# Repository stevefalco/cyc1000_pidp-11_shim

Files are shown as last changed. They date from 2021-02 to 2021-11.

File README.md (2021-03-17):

# cyc1000 pidp-11 shim
This shim allows a PDP-2011 CYC1000 FPGA implementation of the PDP-11 to be used with a PiDP-11 panel.

The PDP2011 FPGA is described here:  https://pdp2011.sytse.net/wordpress/pdp-11/fpga-boards/cyc1000/

The PiDP-11 is described here:  https://obsolescence.wixsite.com/obsolescence/pidp-11

This shim PCB is viewed from the top.  It directly plugs onto the back of the PiDP-11 PCB.  I designed this shim because I had electrical noise problems that caused Ethernet glitches.  I traced the problem to the cables between the CYC1000 and the Digilent Ethernet and SD modules.  This shim eliminates the cables and allows the Digilent modules to connect directly to the shim PCB.

Here are two views of the assembled PCB, showing the Digilent modules extending vertically from the PCB.

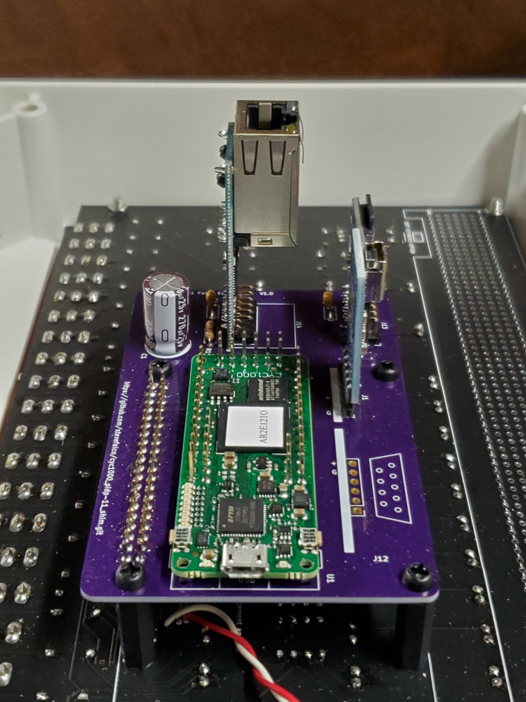
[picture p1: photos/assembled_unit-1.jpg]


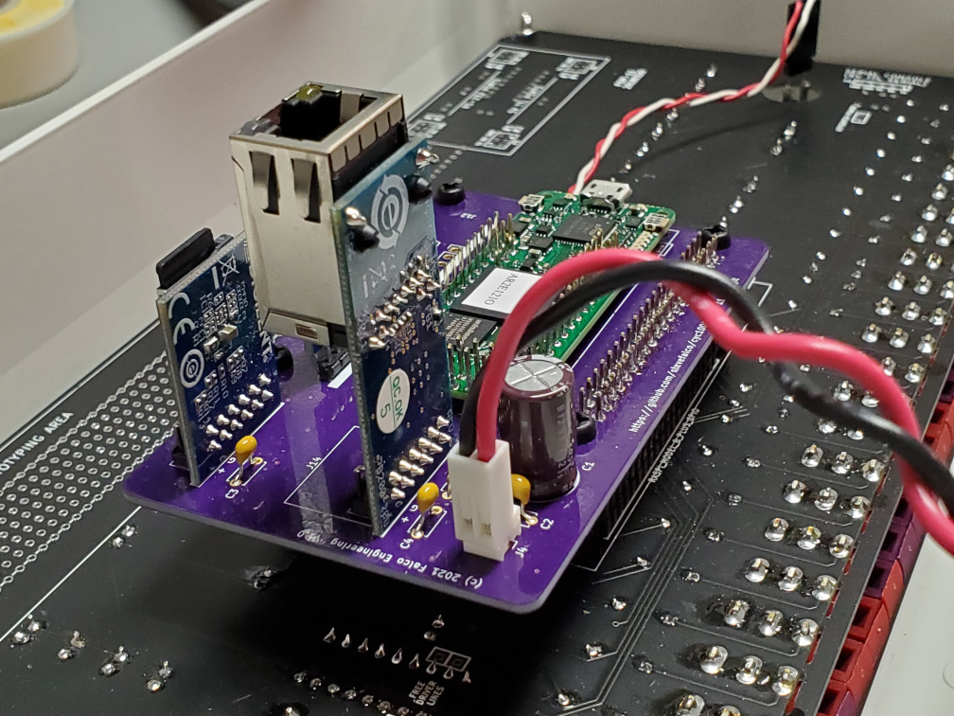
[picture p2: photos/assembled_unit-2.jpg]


J11 must be installed on the bottom of this PCB in order to properly mate with the PiDP-11.  The CYC1000 and all other parts are installed on the top of this PCB.

All capacitors are optional.  I personally prefer to include them.  For C1, the square pad is the positive terminal and the round pad is the negative terminal.

R1 is optional, but according to the Microchip data sheet for the ENC424J600 (see figure 2-9) it really should be installed.

You can only install J1 (FTDI-Friend) or J12 (RS232 PMOD), not both, to avoid conflicts driving the RX1 signal.  In the photos above I installed the FTDI-Friend.

I also designed a housing, suitable for 3D printing, to fit over the modules, since they are of different heights, and they extend through the back panel of the PiDP-11.  The housing named "cover_ftdi_friend.stl" assumes that you will be using an FTDI Friend rather than an RS232 PMOD.  I removed the female connector from the FTDI Friend, and added a right-angle header, so it could directly solder into the shim.  You will have to modify the housing if you do anything different.  You will find the FreeCAD design file and STL in the housing directory.  Here is a photo:

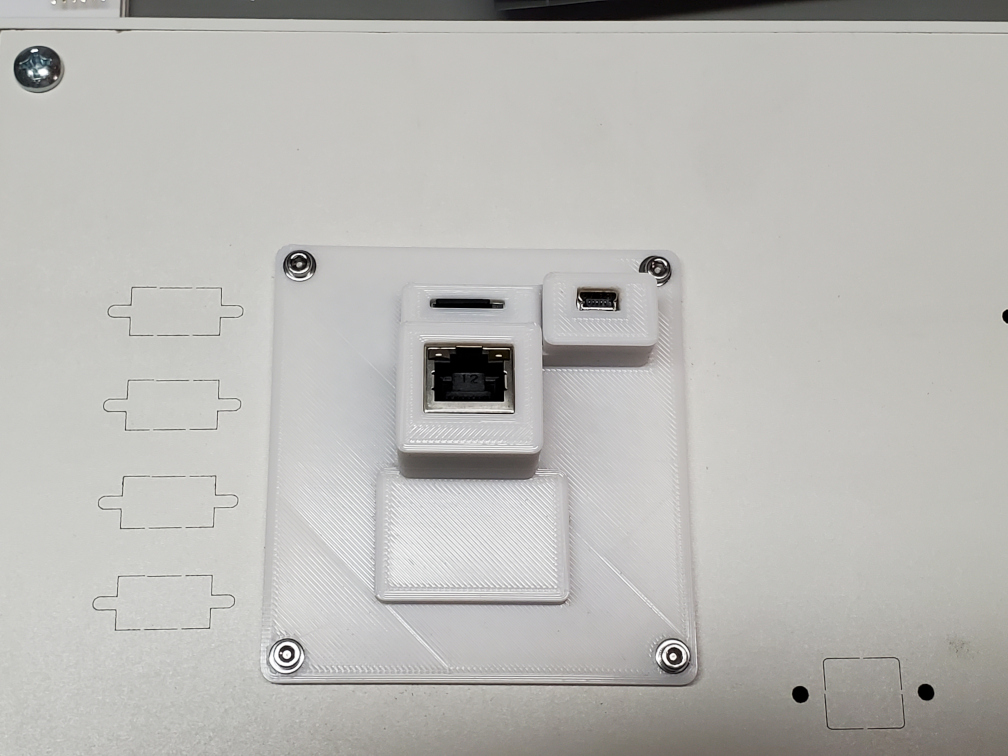
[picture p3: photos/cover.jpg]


There is also a housing named "cover_rs232.stl" which can be used with an RS-232 Digilent PMOD in place of the FTDI friend, if you prefer that interface.

A few last details.  I am using an external power supply rather than powering the unit over USB.  While the CYC1000 allows simultaneous USB and external power - it automatically chooses the higher voltage - I didn't want that, so I modified a bulkhead cable by grinding off the rubber shell at the male end, then cutting the red (+5 volt) connection, and applying epoxy for mechanical strength.  Here is a photo of the modified cable:

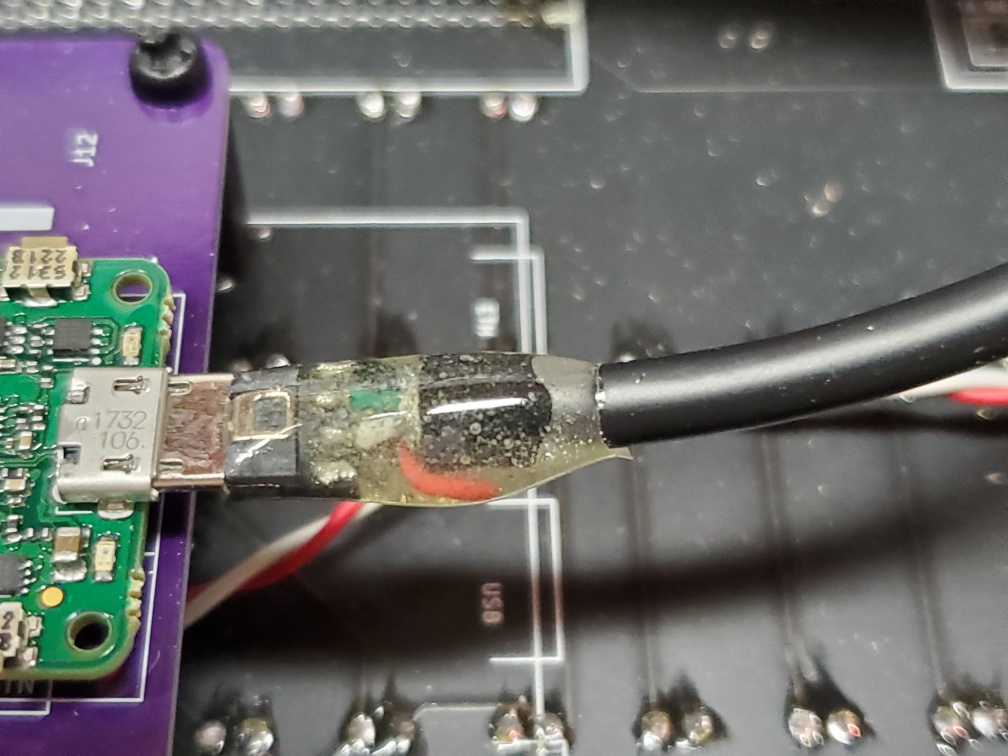
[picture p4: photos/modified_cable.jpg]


And finally, this shim connects the FPGA reset signal to the Pi connector on GPIO19, which has a convenient trace on the PiDP-11 PCB.  In the photos you can see a red/white pair of wires; these connect from GPIO19 to the Key Switch of the front panel.  Thus, the Key Switch can be used to hard-reset the FPGA.

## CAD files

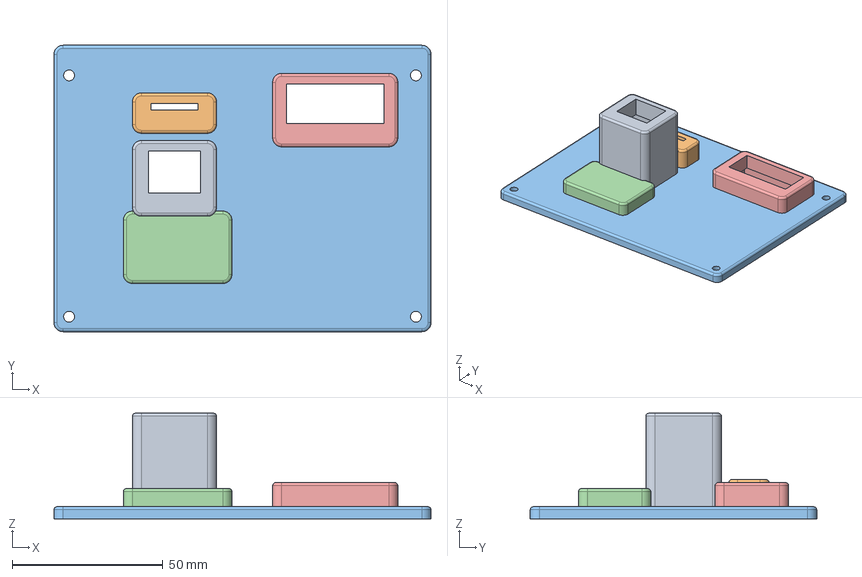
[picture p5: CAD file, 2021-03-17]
housing/cover_rs232.FCStd
125.0 x 95.0 x 35.0 mm
eth_body
sd_body
cover_body
cap_body
rs232_body

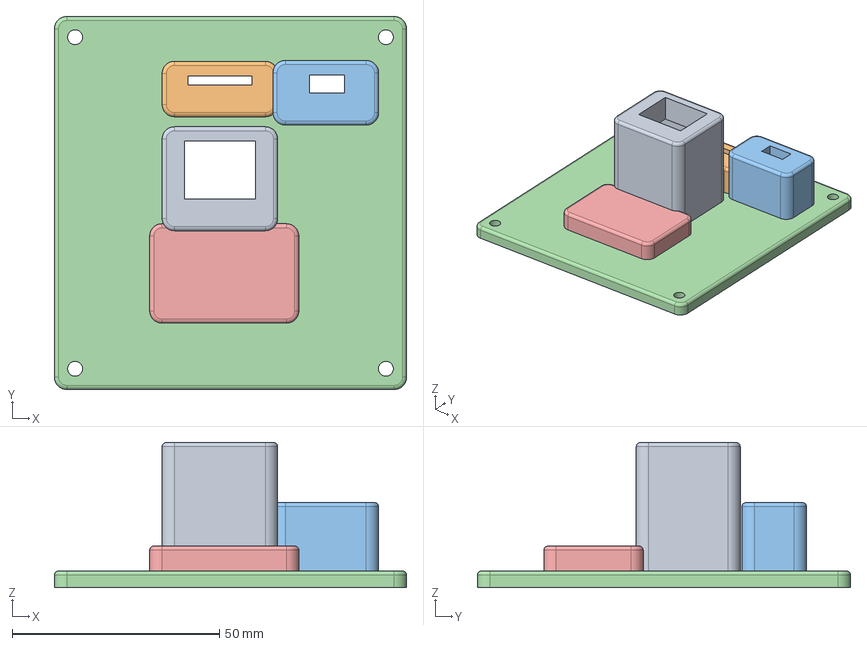
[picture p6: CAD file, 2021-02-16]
housing/cover_ftdi_friend.FCStd
85.0 x 90.0 x 35.0 mm
eth_body
sd_body
friend_body
cover_body
cap_body

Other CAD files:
housing/cover_ftdi_friend.stl
housing/cover_rs232.stl

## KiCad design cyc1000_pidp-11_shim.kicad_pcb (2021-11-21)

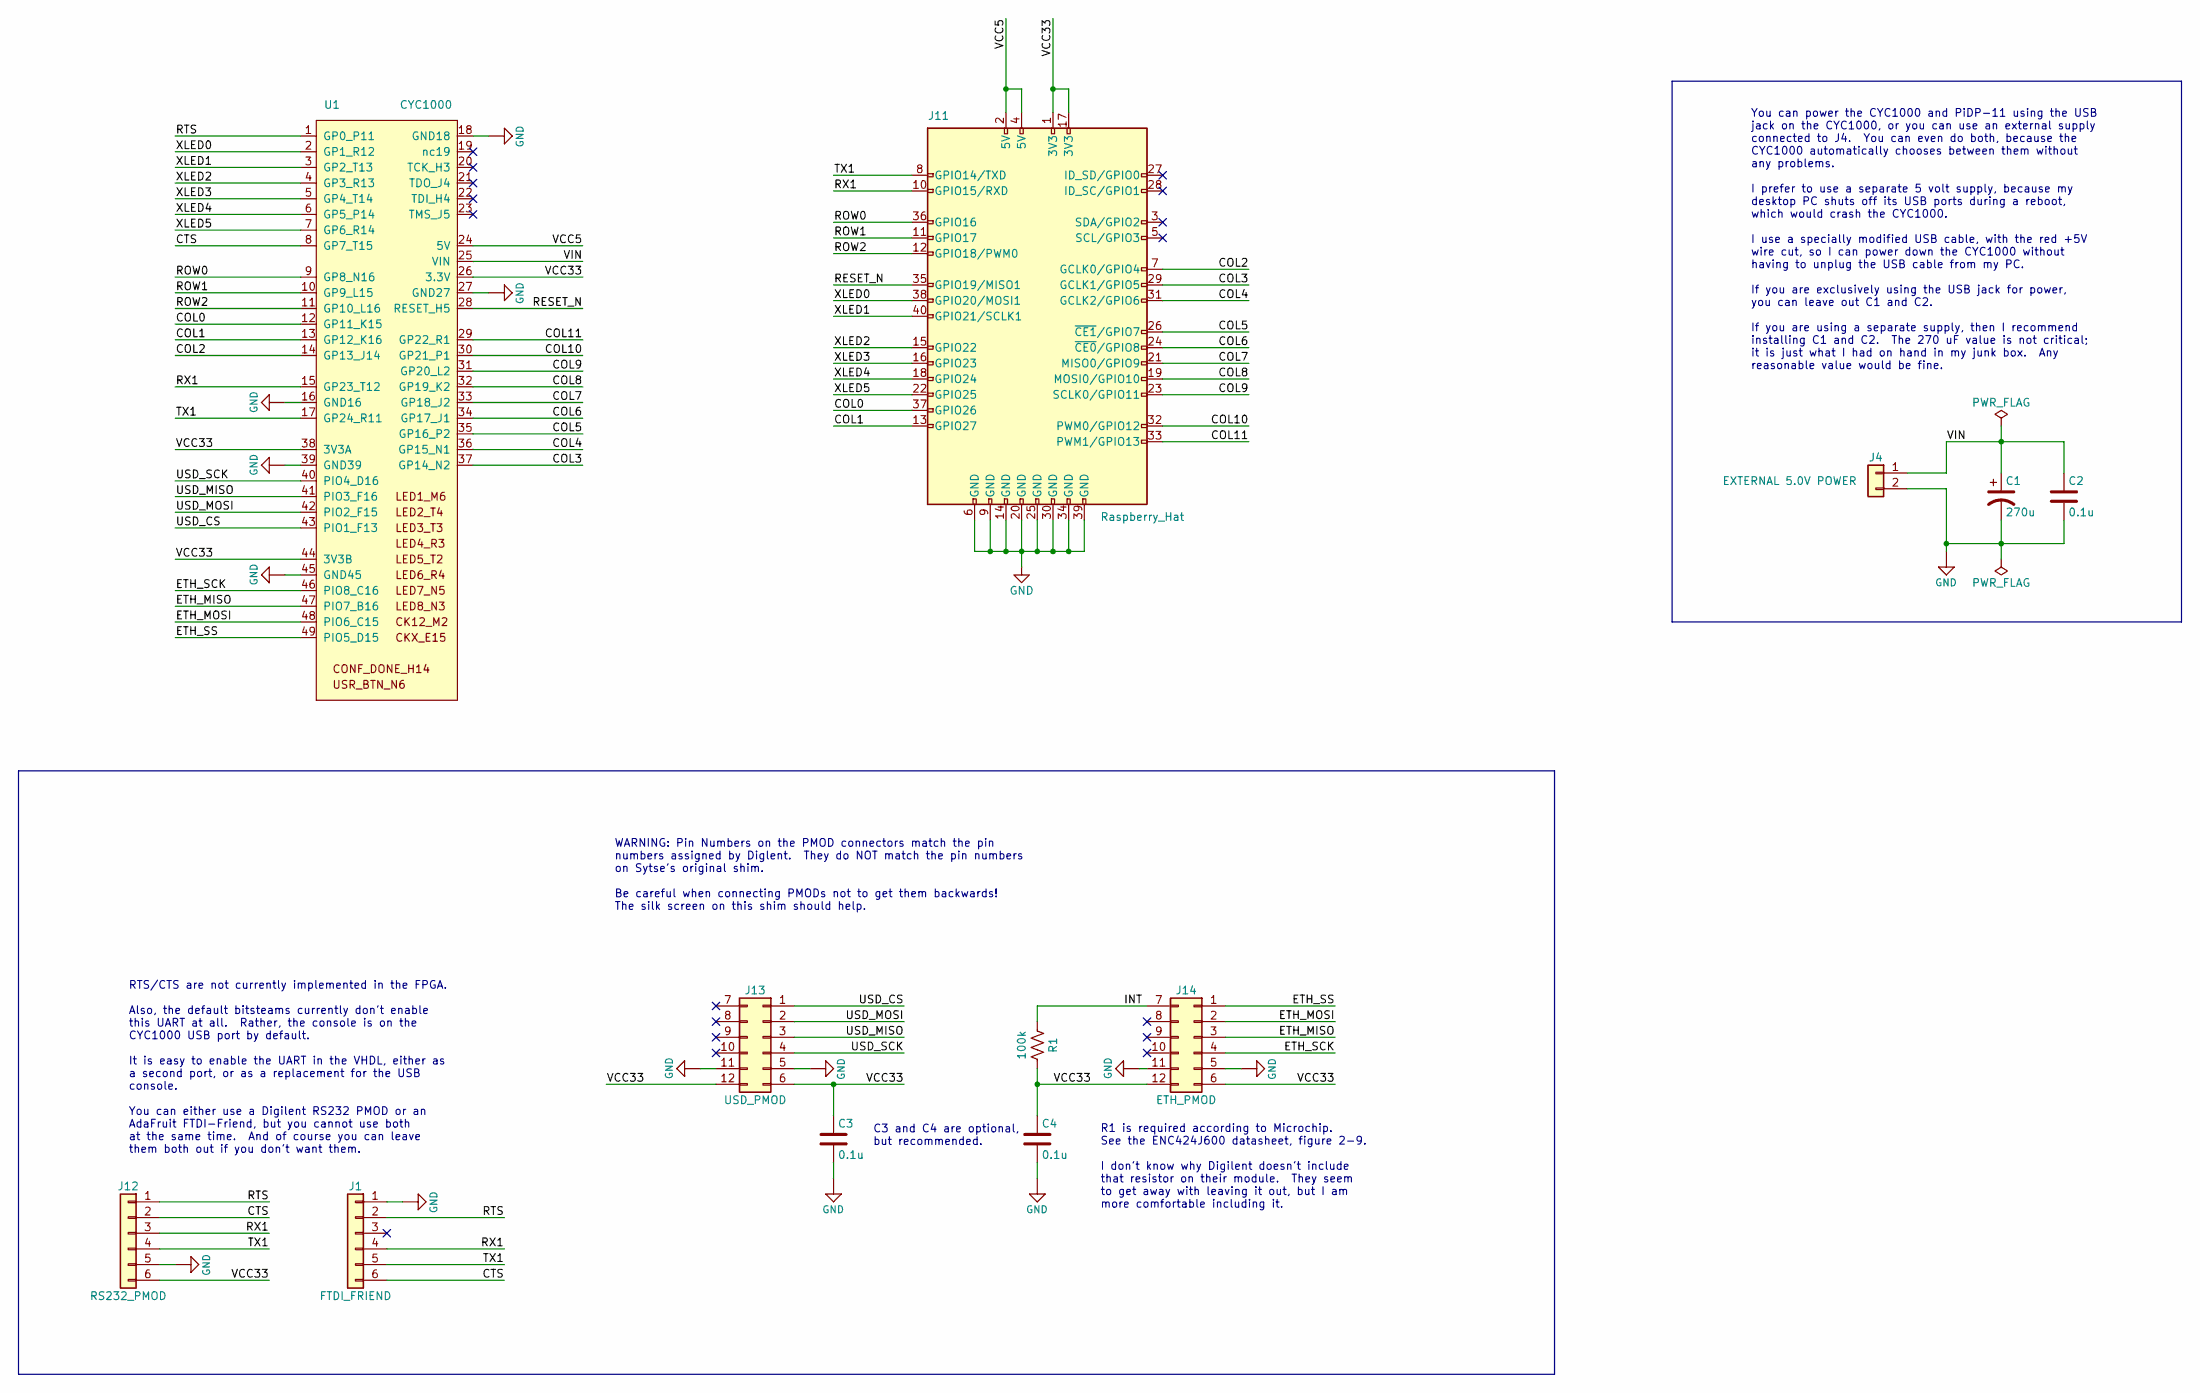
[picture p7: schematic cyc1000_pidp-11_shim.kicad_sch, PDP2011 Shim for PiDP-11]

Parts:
C1: 270u; CP_Radial_D10.0mm_P5.00mm
C2, C3, C4: 0.1u; C_Disc_D5.0mm_W2.5mm_P5.00mm
J1: FTDI_FRIEND; ftdi-friend-1x6
J4: EXTERNAL 5.0V POWER; PinHeader_1x02_P2.54mm_Vertical
J11: Raspberry_Hat; PinHeader_2x20_P2.54mm_Vertical
J12: RS232_PMOD; rs232-1x6
J13: USD_PMOD; uSD-2x6
J14: ETH_PMOD; ethernet-2x6
R1: 100k; R_Axial_DIN0207_L6.3mm_D2.5mm_P7.62mm_Horizontal
U1: CYC1000

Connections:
/COL0: J11.37 (GPIO26), U1.12 (GP11_K15)
/COL1: J11.13 (GPIO27), U1.13 (GP12_K16)
/COL2: J11.7 (GCLK0/GPIO4), U1.14 (GP13_J14)
/COL3: J11.29 (GCLK1/GPIO5), U1.37 (GP14_N2)
/COL4: J11.31 (GCLK2/GPIO6), U1.36 (GP15_N1)
/COL5: J11.26 (~CE1/GPIO7), U1.35 (GP16_P2)
/COL6: J11.24 (~CE0/GPIO8), U1.34 (GP17_J1)
/COL7: J11.21 (MISO0/GPIO9), U1.33 (GP18_J2)
/COL8: J11.19 (MOSI0/GPIO10), U1.32 (GP19_K2)
/COL9: J11.23 (SCLK0/GPIO11), U1.31 (GP20_L2)
/COL10: J11.32 (PWM0/GPIO12), U1.30 (GP21_P1)
/COL11: J11.33 (PWM1/GPIO13), U1.29 (GP22_R1)
/CTS: J1.6, J12.2, U1.8 (GP7_T15)
/ETH_MISO: J14.3, U1.47 (PIO7_B16)
/ETH_MOSI: J14.2, U1.48 (PIO6_C15)
/ETH_SCK: J14.4, U1.46 (PIO8_C16)
/ETH_SS: J14.1, U1.49 (PIO5_D15)
/INT: J14.7, R1.1
/RESET_N: J11.35 (GPIO19/MISO1), U1.28 (RESET_H5)
/ROW0: J11.36 (GPIO16), U1.9 (GP8_N16)
/ROW1: J11.11 (GPIO17), U1.10 (GP9_L15)
/ROW2: J11.12 (GPIO18/PWM0), U1.11 (GP10_L16)
/RTS: J1.2, J12.1, U1.1 (GP0_P11)
/RX1: J1.4, J11.10 (GPIO15/RXD), J12.3, U1.15 (GP23_T12)
/TX1: J1.5, J11.8 (GPIO14/TXD), J12.4, U1.17 (GP24_R11)
/USD_CS: J13.1, U1.43 (PIO1_F13)
/USD_MISO: J13.3, U1.41 (PIO3_F16)
/USD_MOSI: J13.2, U1.42 (PIO2_F15)
/USD_SCK: J13.4, U1.40 (PIO4_D16)
/VCC5: J11.2 (5V), J11.4 (5V), U1.24 (5V)
/VCC33: C3.1, C4.1, J11.1 (3V3), J11.17 (3V3), J12.6, J13.6, J13.12, J14.6, J14.12, R1.2, U1.26 (3.3V), U1.38 (3V3A), U1.44 (3V3B)
/VIN: C1.1, C2.1, J4.1, U1.25 (VIN)
/XLED0: J11.38 (GPIO20/MOSI1), U1.2 (GP1_R12)
/XLED1: J11.40 (GPIO21/SCLK1), U1.3 (GP2_T13)
/XLED2: J11.15 (GPIO22), U1.4 (GP3_R13)
/XLED3: J11.16 (GPIO23), U1.5 (GP4_T14)
/XLED4: J11.18 (GPIO24), U1.6 (GP5_P14)
/XLED5: J11.22 (GPIO25), U1.7 (GP6_R14)
GND: C1.2, C2.2, C3.2, C4.2, J1.1, J4.2, J11.6 (GND), J11.9 (GND), J11.14 (GND), J11.20 (GND), J11.25 (GND), J11.30 (GND), J11.34 (GND), J11.39 (GND), J12.5, J13.5, J13.11, J14.5, J14.11, U1.16 (GND16), U1.18 (GND18), U1.27 (GND27), U1.39 (GND39), U1.45 (GND45)

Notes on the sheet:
You can power the CYC1000 and PiDP-11 using the USB jack on the CYC1000, or you can use an external supply connected to J4. You can even do both, because the CYC1000 automatically chooses between them without any problems. I prefer to use a separate 5 volt supply, because my desktop PC shuts off it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
WARNING: Pin Numbers on the PMOD connectors match the pin numbers assigned by Diglent. They do NOT match the pin numbers on Sytse's original shim. Be careful when connecting PMODs not to get them backwards! The silk screen on this shim should help.
C3 and C4 are optional, but recommended.
RTS/CTS are not currently implemented in the FPGA. Also, the default bitsteams currently don't enable this UART at all. Rather, the console is on the CYC1000 USB port by default. It is easy to enable the UART in the VHDL, either as a second port, or as a replacement for the USB console. You can eit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
R1 is required according to Microchip. See the ENC424J600 datasheet, figure 2-9. I don't know why Digilent doesn't include that resistor on their module. They seem to get away with leaving it out, but I am more comfortable including it.

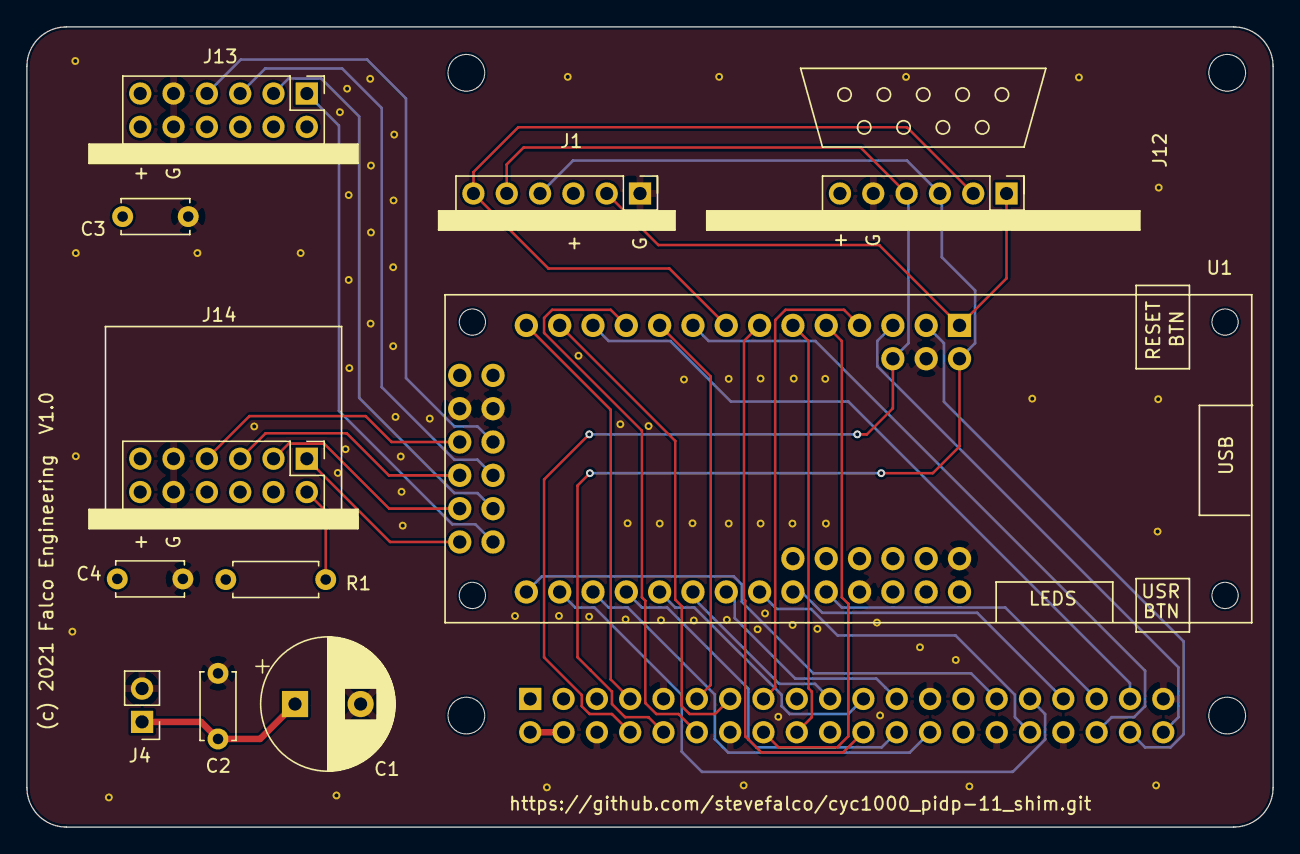
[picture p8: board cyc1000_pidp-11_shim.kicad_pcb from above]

Board: 4 copper layers, 95.0 x 61.0 mm, 16 parts (1 on the bottom side), 39 nets.

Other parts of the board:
MK1, MK2, MK3, MK4: M2.5; MountingHole_2.7mm_M2.5

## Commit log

2021-01-30 Generate gerbers
    [cyc1000_pidp-11_shim-B_Cu.gbl, cyc1000_pidp-11_shim-B_Mask.gbs, cyc1000_pidp-11_shim-B_SilkS.gbo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]
2021-01-30 Remove extra caps, add comments
    [cyc1000_pidp-11_shim-B_Cu.gbl, cyc1000_pidp-11_shim-B_Mask.gbs, cyc1000_pidp-11_shim-B_SilkS.gbo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]
2021-01-30 Ready for manufacture of prototype
    [cyc1000_pidp-11_shim-B_Cu.gbl, cyc1000_pidp-11_shim-B_Mask.gbs, cyc1000_pidp-11_shim-B_SilkS.gbo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]
2021-02-14 Add housing
    [backplate.FCStd, backplate.stl]
2021-02-14 Enlarge holes slightly
    [cyc1000_pidp-11_shim.kicad_pcb]
2021-02-14 Regenerate gerbers
    [cyc1000_pidp-11_shim-B_Cu.gbl, cyc1000_pidp-11_shim-B_Mask.gbs, cyc1000_pidp-11_shim-B_SilkS.gbo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]
2021-02-16 New housing, more modifyable
    [backplate.FCStd, backplate.stl, cover.FCStd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]
2021-02-16 Improved fit of FTDI Friend
    [cover.FCStd, cover.stl]
2021-03-15 Begin alternate cover for RS232 PMOD
    [cover_ftdi_friend.FCStd, cover_rs232.FCStd]
2021-03-16 Fixed basic geometry
    [cover_ftdi_friend.stl, cover_rs232.FCStd, cover_rs232.stl]
2021-03-16 Ready to test
    [cover_rs232.FCStd]
2021-03-16 Tweak position rs232
    [cover_rs232.FCStd, cover_rs232.stl]
2021-03-17 Add proper cover for RS232 PMOD
    [cover_rs232.FCStd, cover_rs232.stl]
2021-03-17 Add the new housing to the readme
2021-11-21 Convert to KiCad 6
    [cyc1000_pidp-11_shim.kicad_pcb, cyc1000_pidp-11_shim.kicad_sch]
2021-11-24 Move to KiCad 6

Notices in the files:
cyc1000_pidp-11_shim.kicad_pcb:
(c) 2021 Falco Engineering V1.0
